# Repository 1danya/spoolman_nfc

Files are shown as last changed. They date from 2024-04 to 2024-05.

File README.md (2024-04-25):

# Spoolman NFC Thingy (Beta)

### Attention!
This is an ongoing project. Currently this page is designed to only provide a basic description and part list. After the initial testing is finished by the early adopters, it will be significantly extended. [Here](https://www.youtube.com/watch?v=UArv1gzjmVA) you can find a basic demo of how this device works.

### Prerequisites
#### Mandatory
1. 3D printer with Klipper firmware (should be accessible via 2.4Ghz WIFI network)
2. ~70g of filament
3. Soldering iron, solder, basic soldering skills 

#### Optional, but highly recommended (assembly instructions would assume you have them)
1. Sharp tweezers
2. Multimeter
3. Wire stripper compatible with AWG24

### Parts list
> Please note that this device is designed to be as cheap as possible. All parts selected to be easily aquired in any part of the world for a fair price. Unfortunately many stores like to be dishonest with their markups so please use the included approximate price to make sure you're not overpaying tenfold. In most cases every item can be purchased both locally or through Aliexpress (fast vs cheaper).

> If possible please get multiples of the cheapest items for spares

1. WEMOS D1 Mini Lite (or clone; USB-C or MicroUSB) $3
2. USB-C or MicroUSB cable (with data lines to upload firmware; any kind to power the device) $1
3. RFID RC522 $2
4. 1m of UTP/FTP ethernet cable (AWG24) $1
5. 5mm Matte RGB led (common cathode) $0.2
6. 12x12x4.3mm momentart pushbutton switch $0.1
7. Five M3x8 button hat screws $0.5
8. 13.54Mhz NFC stickers (NTAG203, NTAG213, NTAG214 etc). In theory any 13.54Mhz should work $0.1-0.2 per piece
9. 1-10k resistor (4.7k for perfection) $0.1

#### Here are some pictures for refence purposes
> Please compare your purchases to these photos to make sure you're getting the right thing

> Also note that Wemos and RC522 should be sold as a kit (as displayed below)

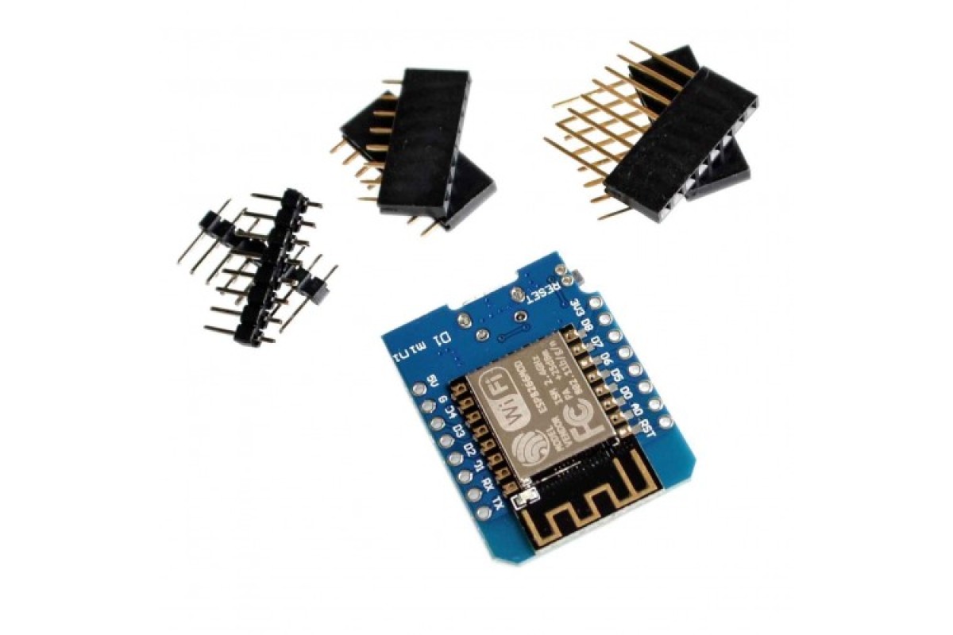
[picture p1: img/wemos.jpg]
WEMOS D1 Mini Lite

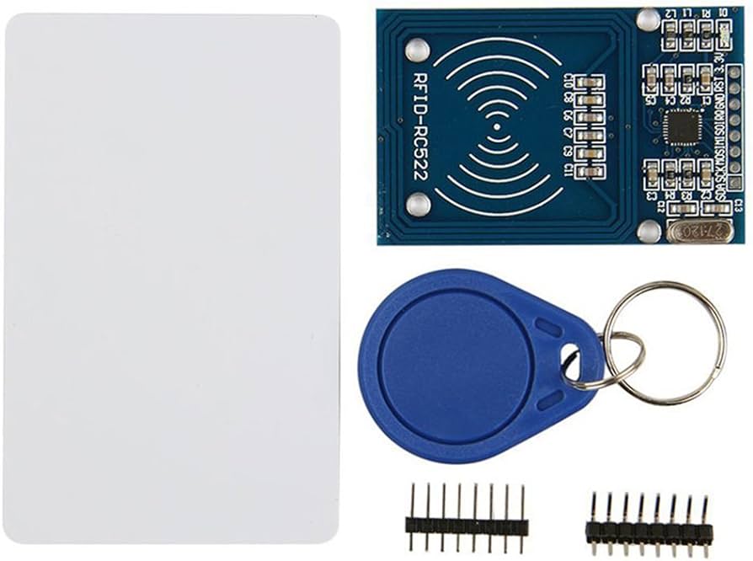
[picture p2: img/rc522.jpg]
RFID RC522

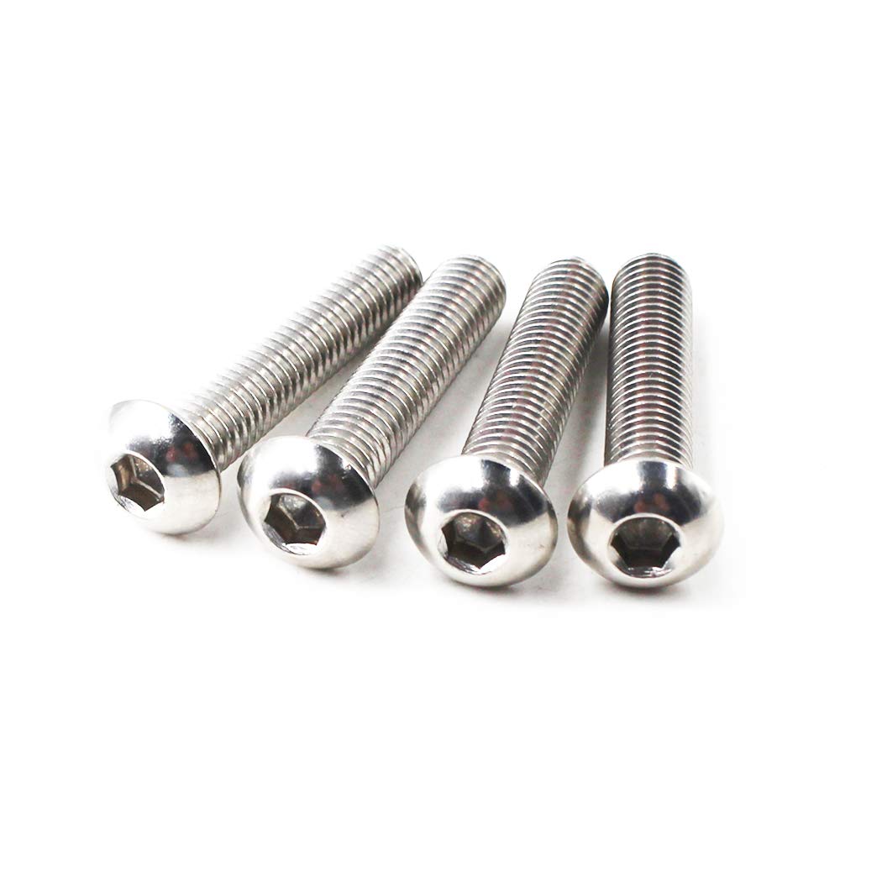
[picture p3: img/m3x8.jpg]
M3x8

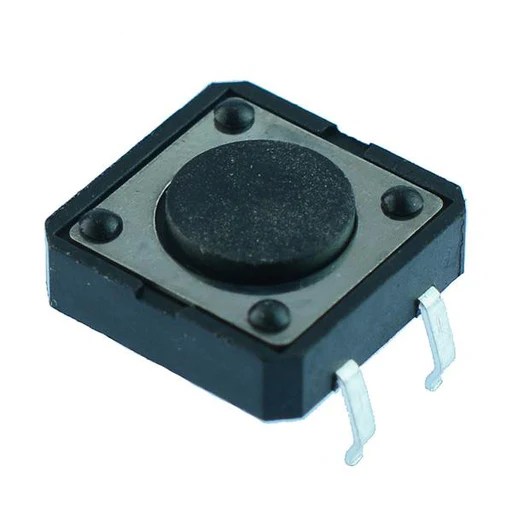
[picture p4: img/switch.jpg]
switch

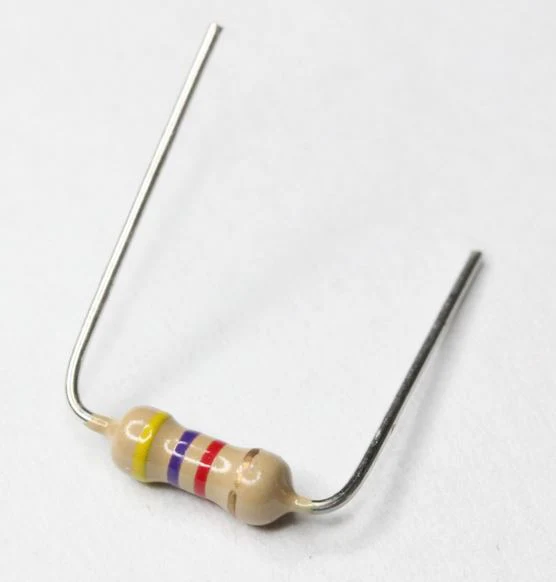
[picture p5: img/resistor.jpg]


### Upcoming changes to repo (TODO)
- Assembly instructions with photos
- STLs
- Source code
- How device works

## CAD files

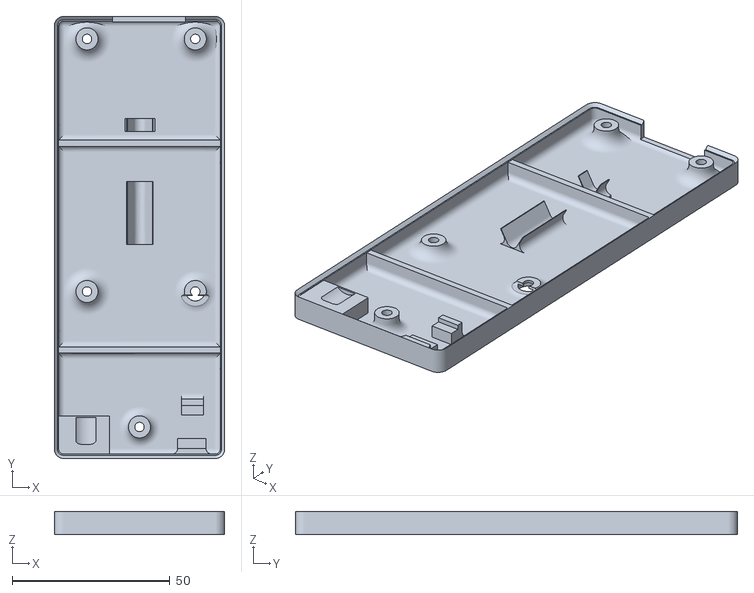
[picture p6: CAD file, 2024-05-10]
STLs/spoolman_nfc_BACK_SIDE.stl
54.0 x 140.0 x 7.35

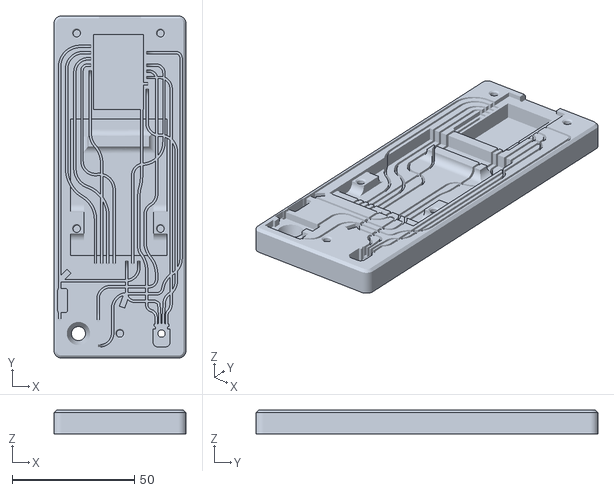
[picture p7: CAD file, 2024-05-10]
STLs/spoolman_nfc_FRONT_COVER_beta.stl
54.0 x 140.0 x 9.70

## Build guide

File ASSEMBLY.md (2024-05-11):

## Assembly Instructions

### Step 0: Before you begin
Please read the instructions to the end before you begin.

You may want to print a small [TEST_PIECE_beta.STL](/STLs/nfc_spoolman_TEST_PIECE_beta.STL). You should be able to insert wires in all of the grooves, that should verify that the real part would work as expected.
- link to Ioans build log

### Step 1: Print STLs
> Tip: Please make sure your printer is properly calibrated (especially PA and flow rate) as it is critical to get proper grooves for wires.

> Tip: You can use any kind of firm filament from PLA to ASA.

> Tip: Print all STLs with default positioning without any supports. Button cap is "turned upside down" in STL so that the visible part is printed on the first layer.

Print [FRONT_COVER_beta.STL](/STLs/nfc_spoolman_FRONT_COVER_beta.STL) and [BUTTON_CAP_beta.STL](/STLs/BUTTON_CAP_beta.STL) first. Put your button cap in its hole and cover it with button like shown in the picture:

> Note: You need to cut the button legs so that it would fit the profile in the front cover. Don't cut too much, just enough to put in into its place.

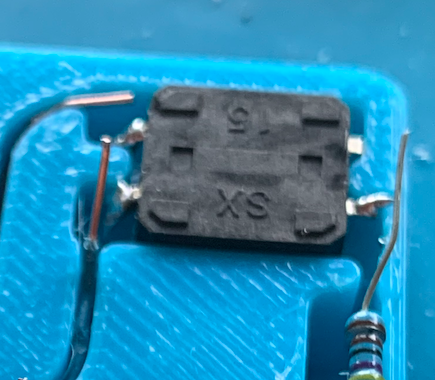
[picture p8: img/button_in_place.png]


Firmly hold the back side of the button with your finger and try to press the button cap from the other side. You should be able to push it but it should not wobble around.
If you can't properly press it or it wobbles around, reprint button cap with a different scale. **Button cap should be flush with the outer surface! It should be not very easy to push by design, because using it involves dangerous operations such as heating your nozzle and pausing the print process.**

You would also need to print the [BACK_SIDE_beta.STL](/STLs/BACK_SIDE_beta.STL), but it can be done at any point of the build.

### Step 2: Laying down the wires
> Tip: Make sure you are using UTP/FTP with a solid core wire. Stranded might work too, but it would be much less convinient for you.

Cut two 20cm pieces of the FTP/UTP cable, carefully remove insulation, foil (if FTP) and uninsulated copper wire. Separate the pairs, but remember to be gentle with it, you don't want to break the wire inside the insulation. You should have 2x4x2=sixteen 20mm pieces by stripping two cables.

This is what you want to end up with, in total you should use 15 wires of different size. All of them are shorter than 20mm and because of that you'll reuse some of the pieces:

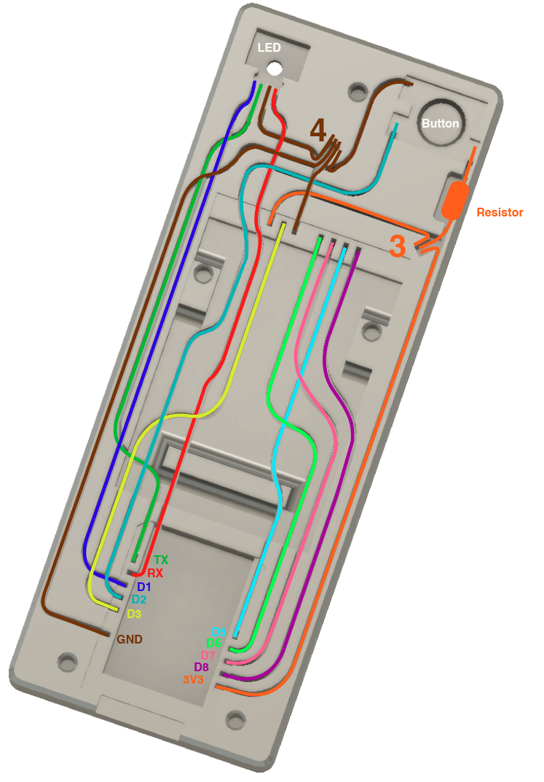
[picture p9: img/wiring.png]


> Note: Number "3" and "4" represent the amount of ends that meet in this point

First you wanna put all the wires that would go into the PCBs because you need to be extra precise with how they are positioned. Strip one end of the 20cm piece (you want to have around 10mm of the naked wire) and insert the wire into the groove.
Carefully poke it with sharp tweezers to make it go inside. You don't need to push it all the way, just make sure it holds.
The begging of the insulation **should** be flush with the beginning of the groove:

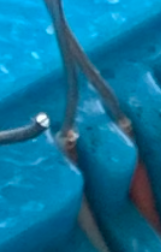
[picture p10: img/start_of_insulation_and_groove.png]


Don't worry if you are not 100% precise just now. You will fix it later when you'll putting the PCBs in.
